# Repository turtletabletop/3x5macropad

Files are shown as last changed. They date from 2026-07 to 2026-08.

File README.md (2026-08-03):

# 3x5skymacropad

Hey everyone! This is my submission for [Hackpad V5](https://hackpad.hackclub.com/), a YSWS program in [Hack Club](https://hackclub.com/).

This macropad is a custom-built 3x5 ortholinear hot-swappable keyboard built off of the Seeed Studio XIAO RP2040 with a small OLED display. It uses Kailh Hot Swap Sockets, so it supports a variety of MX-style switches and uses QMK firmware. It's intended to mimic the Sky: Children of the Light digital music pad in-game.

## Features
- 15 programmable keys
- 128x32 OLED screen
- rad pcb silkscreen art
- QMK firmware
- a 3-degree tilt for more comfortable access to all the keys

## CAD + Case
### [Onshape link: <--- GO CLICK THIS!!!! It's a link to my CAD you can see online without downloading!!!](https://cad.onshape.com/documents/501449d828c00fab2d0b549b/w/615af9d6281a356a4f3616d7/e/420bb48ea47a66a72aa17e60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)



I used Onshape for the CAD because I have previously used Onshape for FRC, and I thought Fusion360 was for nerds + online link sharing is fun!

Note that the mounting plate is intended to be fully transparent and made of acrylic/resin/any other clear material that can be used for a mounting plate. First time using Onshape for anything outside of robotics. Kept the case pretty simple. 

### Case Assembly:
The case is assembled by putting the heat set inserts in the top, and the bolts in the bottom.



## PCB
The entire PCB was made in KiCad! Note that I used [ScottoKeeb's KiCad library](https://github.com/joe-scotto/scottokeebs/tree/main/Extras/ScottoKicad) for the footprints and symbols because I was following [his guide](https://youtu.be/8WXpGTIbxlQ?). I had a lot of fun adding the silkscreen art for this; I just ripped a bunch of pictures from indie games I love + SkyCOTL. First time making a PCB! 



*without filled zones*



*with filled zones*

## PCB Schematic
dunno what to say here honestly just copied skottokeeb's guide for the most part



## Specifications
### Hardware used:
- Seeed Studio XIAO RP2040
- Kailh Hot Swap Sockets
- 128x32 OLED Screen

### Bill of Materials (BOM):
- 15x Cherry MX Switches
- 15x DSA Keycaps
- 1x Seeed Studio XIAO RP2040
- 4x M3x16mm SHCS Bolts
- 4x M3x5x4 Heatset inserts
- 1x 0.91" 128x32 OLED Display

### Inspiration:
This was mainly inspired by Sky: Children of the Light's in-game music pad. When you play an instrument in-game, a 3x5 tiled grid shows up where you can press each tile to play a musical note.



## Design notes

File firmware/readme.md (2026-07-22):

# 3x5skymacropad

3x5skymacropad

*A short description of the keyboard/project*

* Keyboard Maintainer: [Eleos Chung](https://github.com/turtletabletop)
* Hardware Supported: *The PCBs, controllers supported*
* Hardware Availability: *Links to where you can find this hardware*

Make example for this keyboard (after setting up your build environment):

    make 3x5skymacropad:default

Flashing example for this keyboard:

    make 3x5skymacropad:default:flash

See the [build environment setup](https://docs.qmk.fm/#/getting_started_build_tools) and the [make instructions](https://docs.qmk.fm/#/getting_started_make_guide) for more information. Brand new to QMK? Start with our [Complete Newbs Guide](https://docs.qmk.fm/#/newbs).

## Bootloader

Enter the bootloader in 3 ways:

* **Bootmagic reset**: Hold down the key at (0,0) in the matrix (usually the top left key or Escape) and plug in the keyboard
* **Physical reset button**: Briefly press the button on the back of the PCB - some may have pads you must short instead
* **Keycode in layout**: Press the key mapped to `QK_BOOT` if it is available

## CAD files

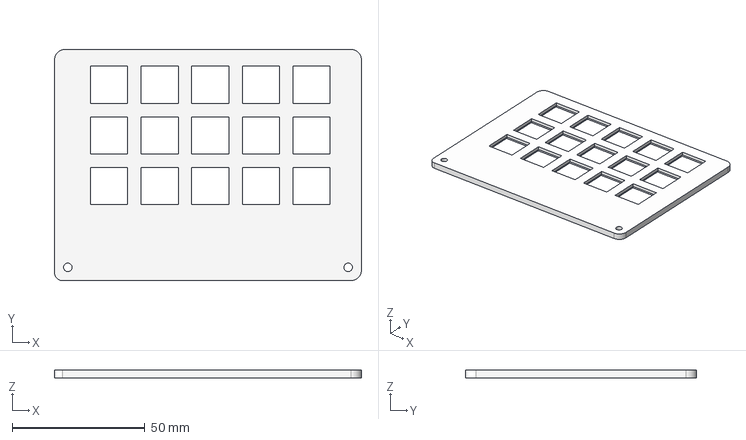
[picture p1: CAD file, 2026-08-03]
production/3x5macropad8 - mounting plate.step
115.5 x 87.0 x 3.00 mm

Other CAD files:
cad/3x5skymacropadCASEandPCB.step

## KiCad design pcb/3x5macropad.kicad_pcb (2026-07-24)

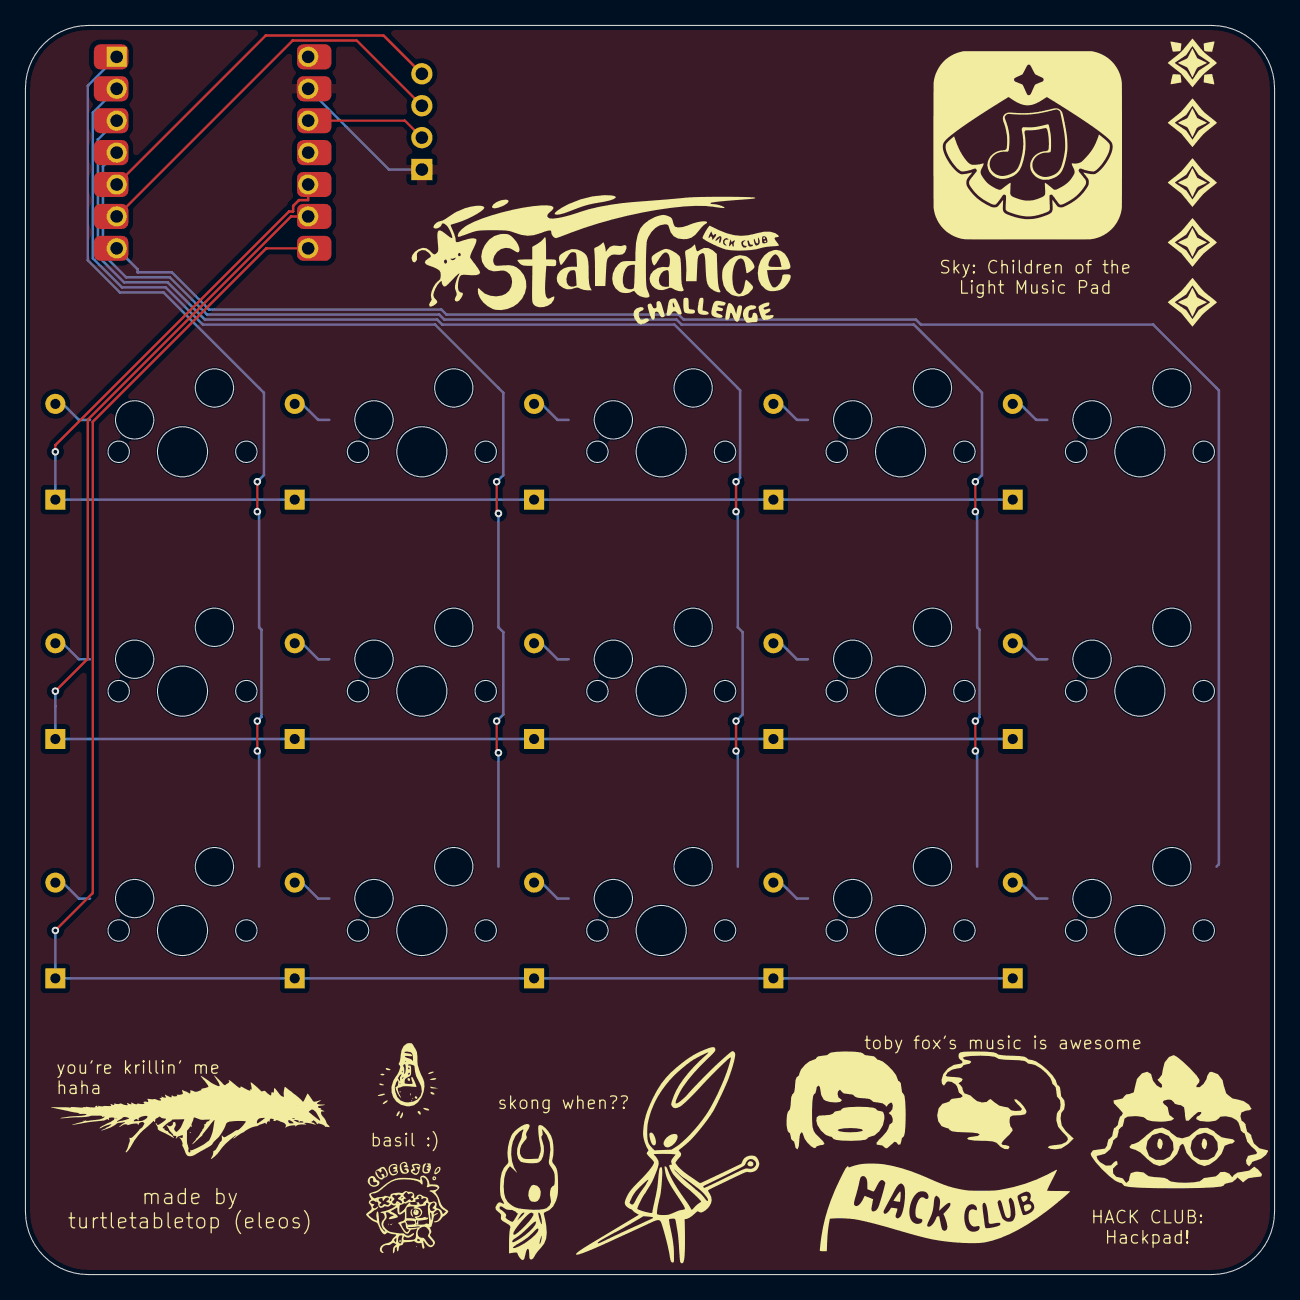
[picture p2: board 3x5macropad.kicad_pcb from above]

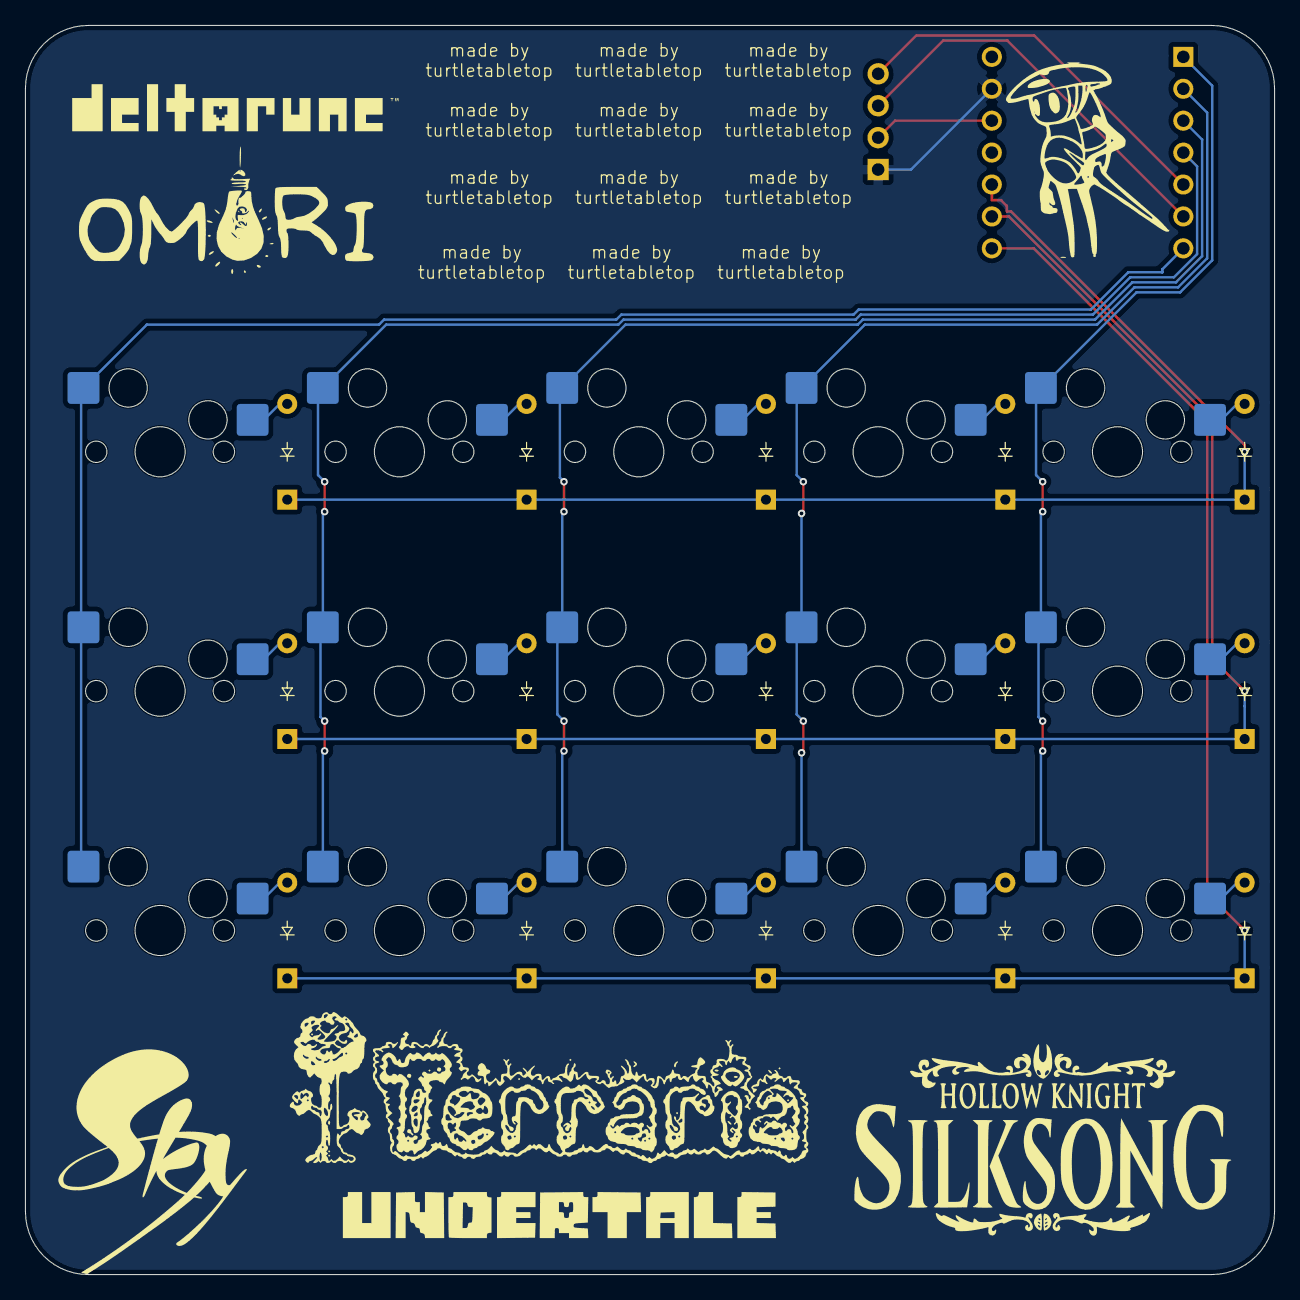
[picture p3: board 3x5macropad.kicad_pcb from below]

Board: 2 copper layers, 99.4 x 99.4 mm, 32 parts (30 on the bottom side), 27 nets.

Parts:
D1, D2, D3, D4, D5, D6, D7, D8, D9, D10, D11, D12, D13, D14, D15: Diode_DO-35
J1: OLED_128x32
S1, S2, S3, S4, S5, S6, S7, S8, S9, S10, S11, S12, S13, S14, S15: MX100H
U2: MCU_Seeed_XIAO_RP2040; Seeed_XIAO_RP2040

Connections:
/Column 0: S1.1, S6.1, S11.1, U2.7 (PB08_A6_D6_TX)
/Column 1: S2.1, S7.1, S12.1, U2.4 (PA11_A3_D3)
/Column 2: S3.1, S8.1, S13.1, U2.3 (PA10_A2_D2)
/Column 3: S4.1, S9.1, S14.1, U2.2 (PA4_A1_D1)
/Column 4: S5.1, S10.1, S15.1, U2.1 (PA02_A0_D0)
/Row 0: D1.1 (K), D2.1 (K), D3.1 (K), D4.1 (K), D5.1 (K), U2.10 (PA5_A9_D9_MISO)
/Row 1: D6.1 (K), D7.1 (K), D8.1 (K), D9.1 (K), D10.1 (K), U2.9 (PA7_A8_D8_SCK)
/Row 2: D11.1 (K), D12.1 (K), D13.1 (K), D14.1 (K), D15.1 (K), U2.8 (PB09_A7_D7_RX)
/oled 3.3v: J1.2 (VCC), U2.12 (3V3)
/oled ground: J1.1 (GND), U2.13 (GND)
/oled serial clock: J1.3 (SCL), U2.6 (PA9_A5_D5_SCL)
/oled serial data: J1.4 (SDA), U2.5 (PA8_A4_D4_SDA)
unnamed: D1.2 (A), S1.2
unnamed: D2.2 (A), S2.2
unnamed: D3.2 (A), S3.2
unnamed: D4.2 (A), S4.2
unnamed: D5.2 (A), S5.2
unnamed: D6.2 (A), S6.2
unnamed: D7.2 (A), S7.2
unnamed: D8.2 (A), S8.2
unnamed: D9.2 (A), S9.2
unnamed: D10.2 (A), S10.2
unnamed: D11.2 (A), S11.2
unnamed: D12.2 (A), S12.2
unnamed: D13.2 (A), S13.2
unnamed: D14.2 (A), S14.2
unnamed: D15.2 (A), S15.2

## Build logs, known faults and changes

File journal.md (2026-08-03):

## Day 1 (July 18, 2026) (~5 hours)

mainly followed scottokeebs's guide for the most part and was able to:
- assembled the first draft of the PCB for the keyboard



not finalized yet!
- made a rudimentary case for the PCB



does not look good, also the pcb slows down onshape so much

### design considerations:
note that I want the keys to be hotswappable now so I need to change the configuration and figure out which mounts are needed
hotswappable keys are nice for testing future switches
- https://jlcpcb.com/partdetail/Kailh-CPG151101S111/C5184526
- kalih == cherry mx switches standard
- https://github.com/AcheronProject/acheron_MXH.pretty (footprint?)

purple and pink case, with blue pcb, lavender keycaps

figure out how to get pcb with traces so that I can tell where the pcb art is gonna be



### switches/keycap wants for the "first" iteration:
- **silent** "creamy" linear switches would be ideal
- 45 (gf) gram force similar to what a midi offers
- lavender keycaps

Order from JLCPCB because they can assemble the PCB with the parts soldered on for me

### things to work on tomorrow: 
- figure out the full PCB design, finalize it
- design a good-looking case for the board
- start looking at qmk

## Day 2 (July 19, 2026) (~6 hours)
decided I should go with the kit parts except for the keycaps (i really want colored keycaps) and kailh sockets

also there will be no pcb assembly from jlcpcb because soldering these things aren't really that hard

time to rewire a lot of stuff

I decided not to go with under keycap LEDS because they'd take too long to figure out how they work and I can't be bothered with a rotary encoder either

ideally: https://milktooth.com/products/milky-pro-silent-linear

no way i have to add holes for the screws i forgot :(

values for later:
- -6.187494 in x
- 3.093757 in y

ok, at the end of this day I kind of wasted a bunch of time trying to place a pcb into a board with all the components which was very bad for my time usage because it didn't even end up working

## misc links for days 1-2 because i forgot
- https://github.com/AcheronProject/acheron_MXH.pretty 

although this does provide the footprint for kailh mx-style sockets, it doesn't provide you with the 3d model which I had to find on my own. Originally I found it through some shady ahh website here: https://www.snapeda.com/parts/PG151101S11/Kailh/view-part/?company=hack+club& **but I realized after I inserted the 3d model that the scottokeebs library i downloaded already has the model**

Note that for both the website and the scottokeebs library the models need to be manually aligned inside kicad

## Day 3 (July 20, 2026) (~8 hours)
i kind of forgot that today was a new day because I was up at 2:00 am today working on this

anyways i'll be modeling my journal entries better hopefully because i found THIS: https://codex.hackclub.com/shipping/example-journal/
a lot of hack club is buried under niche keyword searches and random findings a lot of the time

updates to the pcb:
- i changed the keycaps to the DSA kit keycaps given in hackpad
- thats all?

damn i really thought i could be done by today but it's really not the case

speaking of cases: that's really what I need to work on today! 

I found out by searching that there are many different ways of mounting your PCB to your case: important link here- https://shop.marvo-tech.com/blogs/all/custom-mechanical-keyboards-parts

here's a tldr for that page-- they have a cheat sheet right here



I've seen the keyword sandwich mount before in the hackpad channel so that's the one I'm going for, also I found scottokeebs video on making cases and mounting plates so i'm definitely going to watch it

edit: this before the next link- https://www.keyboard-layout-editor.com/#/

i found this mounting plate site during my math lecture: https://builder-docs.swillkb.com/

so like it turns out i don't actually need the screws in the pcb so darn.

i figured out how to put the pcb in onshape that so it actually runs in onshape wahoo (why did this take forever)



first actual iteration of the board! also i colored it purple later

## Day 4 (July 21, 2026) (~5 hours)
Hey! so it's my exam day so I don't have a lecture to go to for today which is kind of great because I can do more things and also my violin lesson was moved to another day this week so that's great

as of right now, I've been checking the edges of all the parts to make sure that they work well and adjusting them if they don't fit the shape I want



*the edges i've been fixing*

I also figured out how to make better holes for the screws that I'll be receiving with the kit (don't extrude your holes with the 'plates' in order to adjust the length accordingly) also added an extra screw because I thought it wasn't enough



*added 5 screw holes into the case*

update: removed the screw in the middle of the case because it collided with the pcb 



and also i added a usb-c cutout!



also i added more decals to my board!

## day 5 (July 22, 2026) (~4hr)
I have no idea what i'm doing but i was able to get qmk setup with a lot of patience and waiting for files to load, and now i have a rudimentary firmware to push




holy freaking sheet basically went through the pricing for the macroboard and found out that i sized my pcb wrong so i was getting a much higher quote at jlcpcb than what i was actually supposed to get, so i had to redo the edge cuts for the pcb



*the new square rather than rectangle pcb*

i was also worried about the clear part of my mounting board so i found out that jlcpcb also 3d prints resin parts so hopefully i can use their services because it was pretty cheap from what i saw

also about resizing my pcb, i had to completely redo the case. thankfully, i've learned from my past experiences and actually know what i want. basically i was walking blind through my case last time which helped me know a lot about what i needed for my case this time, and decided to simplify it a ton more because the case was pretty complicated last time. also i know how to simplify the pcb so that it actually runs on my onshape this time :)


*the new simplified case*

i also added graphics to the back that nobody will see! yippee 


## day 6 (July 23, 2026) (couple of hours?)

tooooday's shipping day! I have 90% of the stuff ready i just need to upload everything onto this github and submit the form. Currently i've just been working through tiny issues here and there that i can see are problems

the case looks nice (as expected :)))) )


## day 7 (August 2nd, 2026) (15 mins)
hopefully the final update. I noticed that some of the tolerances of the case were off and decided to adjust the geometry so that there was >=0.2mm gap between the PCB and the case. I only adjusted the mounting plate and didn't touch anything else.



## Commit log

2026-08-03 Add files via upload
    adjusted the tolerances
    [3x5macropad8 - mounting plate (1).step]
2026-08-03 Rename 3x5macropad8 - mounting plate (1).step to 3x5macropad8 - mounting plate.step
    [3x5macropad8 - mounting plate.step]
